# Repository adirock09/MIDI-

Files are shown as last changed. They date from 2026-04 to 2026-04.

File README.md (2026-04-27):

# MIRA-Custom-MIDI-
<br>

<br>
I started with layout It has 40 Keys in 10 x 4 Layout.Top two layers are for High octave and bottom two for Low octave the three sliders are for Filter,Reverb,Modulation and three encoders are for Volume, Tempo, Track control.I used Matrix so it uses less Gpios, It is based on Raspberry Pico.
PCB made in Kicad and modeling done in Fusion 360. Firmware is written in circuit python and uses Adafruit MIDI Library.

## Bill of Materials (BOM)

| Index | Component | Part Number | Source | Quantity | Unit Price (USD) | Total Price (USD) | Notes |
|---|---|---|---|---|---|---|---|
| 1 | Bittersweet Switch | MX2A-HC1B | stackskb.com | (Pack of 45)  × 1 | 17 | 17 | |
| 2 | Keycaps Set | MX Compatible Keycaps | meckeys.com | 8(pack of 5) | 1.1 | 8.8 | For 40 keys |
| 3 | Signal Diode | 1N4148TR | makerbazar.in | 4(pack of 10) | 0.15 | 0.6 | |
| 4 | Raspberry Pi Pico | SC0917 | makerbazar.in | 1 | 6.12 | 6.12 | |
| 5 | Slide Potentiometer 10K | PTL60-15R0-103B2 | Existing | 3 | 0 | Already have | |
| 6 | PCB Fabrication | SeedStudio PCB | seeedstudio.com | 1 | 51.11 |51.11 | |
| 7 | PCB Shipping | seedstudio Shipping | seeedstudio.com | 27.37 |  | 27.37 | |
| 8 | Rotary Encoder | EC11 | Existing | 3 | 0 | 0 | Already have |
| 9 | M3 Screws | M3x16mm | Existing | 4 | 0 | 0 | Already have |
| 10 | M3 Heat-set Inserts | M3 Heatset | Existing | 4 | 0 | 0 | Already have |

### Total Project Cost
**$111**

## Schematic & PCB
<br>
<br>


<br>

## 3d Render
<br>

<br>

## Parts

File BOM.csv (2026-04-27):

Index | Component | Part Number | Source | Quantity | Unit Price (USD) | Total Price (USD) | Notes
1 | Cherry MX Mechanical Keyswitch | MX2A-HC1B | stackskb.com | (Pack of 45) × 1 | 17 | 17
2 | Keycaps Set | MX Compatible Keycaps | meckeys.com | 8(pack of 5) | 1.1 | 8.8 | For 40 keys
3 | Signal Diode | 1N4148TR | makerbazar.in | 4(pack of 10) | 0.15 | 0.6
4 | Raspberry Pi Pico | SC0917 | makerbazar.in | 1 | 6.12 | 6.12
5 | Slide Potentiometer 10K | PTL60-15R0-103B2 | already have | 3 | 0 | 0
6 | PCB Fabrication | SeedStudioPCB | seeedstudio.com | 1 | 51.11 | 51.11
7 | PCB Shipping | SeedStudioPCB Shipping | seeedstudio.com | 1 | 27.37 | 27.37
8 | Rotary Encoder | EC11 | Existing | 3 | 0 | 0 | Already owned
9 | M3 Screws | M3x16mm | Existing | 4 | 0 | 0 | Already owned
10 | M3 Heat-set Inserts | M3 Heatset | Existing | 4 | 0 | 0 | Already owned
11 | Total |  |  |  |  | $111

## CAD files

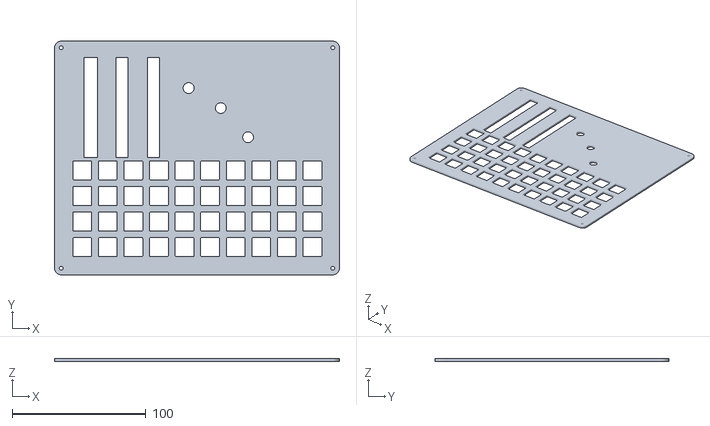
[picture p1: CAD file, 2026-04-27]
MIDI Controller/Production/TOP.stl
213.4 x 175.0 x 2.00

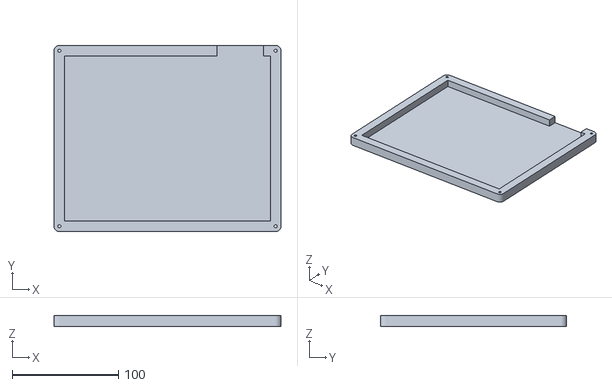
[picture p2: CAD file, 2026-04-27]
MIDI Controller/Production/BASE.stl
213.4 x 175.0 x 10.0

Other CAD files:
MIDI Controller/CAD/MIDI.f3d

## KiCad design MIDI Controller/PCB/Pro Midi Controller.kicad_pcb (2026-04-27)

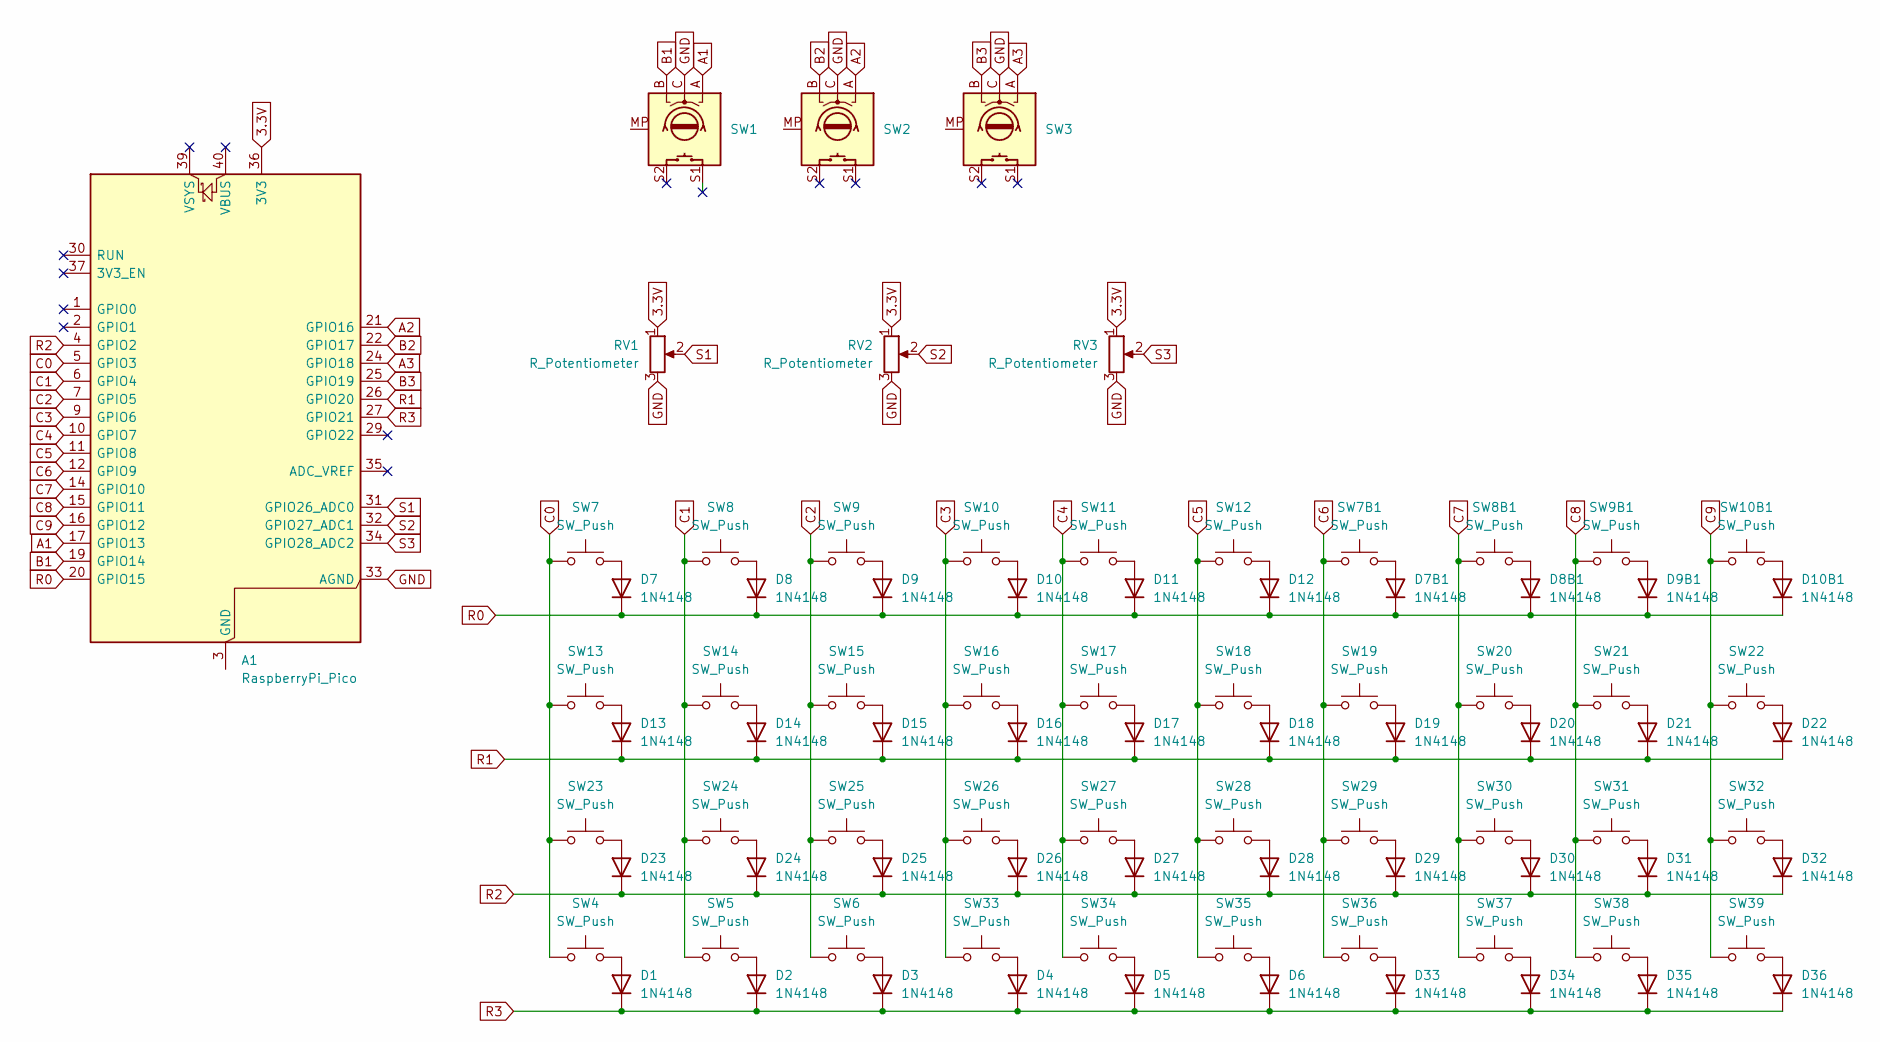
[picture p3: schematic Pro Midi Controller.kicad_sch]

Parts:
A1: RaspberryPi_Pico; RaspberryPi_Pico_Common_Unspecified
D1, D2, D3, D4, D5, D6, D7, D7B1, D8, D8B1, D9, D9B1, D10, D10B1, D11, D12, D13, D14, D15, D16, D17, D18, D19, D20, D21, D22, D23, D24, D25, D26, D27, D28, D29, D30, D31, D32, D33, D34, D35, D36: 1N4148; D_DO-35_SOD27_P7.62mm_Horizontal
RV1, RV2, RV3: R_Potentiometer; Potentiometer_Bourns_PTA6043_Single_Slide
SW1, SW2, SW3: RotaryEncoder_Switch_MP; RotaryEncoder_Alps_EC11E-Switch_Vertical_H20mm
SW4, SW5, SW6, SW7, SW7B1, SW8, SW8B1, SW9, SW9B1, SW10, SW10B1, SW11, SW12, SW13, SW14, SW15, SW16, SW17, SW18, SW19, SW20, SW21, SW22, SW23, SW24, SW25, SW26, SW27, SW28, SW29, SW30, SW31, SW32, SW33, SW34, SW35, SW36, SW37, SW38, SW39: SW_Push; SW_Cherry_MX_1.00u_PCB

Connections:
3.3V: A1.36 (3V3), RV1.1, RV2.1, RV3.1
A1: A1.17 (GPIO13), SW1.A
A2: A1.21 (GPIO16), SW2.A
A3: A1.24 (GPIO18), SW3.A
B1: A1.19 (GPIO14), SW1.B
B2: A1.22 (GPIO17), SW2.B
B3: A1.25 (GPIO19), SW3.B
C0: A1.5 (GPIO3), SW4.1, SW7.1, SW13.1, SW23.1
C1: A1.6 (GPIO4), SW5.1, SW8.1, SW14.1, SW24.1
C2: A1.7 (GPIO5), SW6.1, SW9.1, SW15.1, SW25.1
C3: A1.9 (GPIO6), SW10.1, SW16.1, SW26.1, SW33.1
C4: A1.10 (GPIO7), SW11.1, SW17.1, SW27.1, SW34.1
C5: A1.11 (GPIO8), SW12.1, SW18.1, SW28.1, SW35.1
C6: A1.12 (GPIO9), SW7B1.1, SW19.1, SW29.1, SW36.1
C7: A1.14 (GPIO10), SW8B1.1, SW20.1, SW30.1, SW37.1
C8: A1.15 (GPIO11), SW9B1.1, SW21.1, SW31.1, SW38.1
C9: A1.16 (GPIO12), SW10B1.1, SW22.1, SW32.1, SW39.1
GND: A1.33 (AGND), RV1.3, RV2.3, RV3.3, SW1.C, SW2.C, SW3.C
unnamed: A1.3 (GND), A1.8 (GND), A1.13 (GND), A1.18 (GND), A1.23 (GND), A1.28 (GND), A1.38 (GND)
unnamed: D1.2 (A), SW4.2
unnamed: D2.2 (A), SW5.2
unnamed: D3.2 (A), SW6.2
unnamed: D4.2 (A), SW33.2
unnamed: D5.2 (A), SW34.2
unnamed: D6.2 (A), SW35.2
unnamed: D7.2 (A), SW7.2
unnamed: D7B1.2 (A), SW7B1.2
unnamed: D8.2 (A), SW8.2
unnamed: D8B1.2 (A), SW8B1.2
unnamed: D9.2 (A), SW9.2
unnamed: D9B1.2 (A), SW9B1.2
unnamed: D10.2 (A), SW10.2
unnamed: D10B1.2 (A), SW10B1.2
unnamed: D11.2 (A), SW11.2
unnamed: D12.2 (A), SW12.2
unnamed: D13.2 (A), SW13.2
unnamed: D14.2 (A), SW14.2
unnamed: D15.2 (A), SW15.2
unnamed: D16.2 (A), SW16.2
unnamed: D17.2 (A), SW17.2
unnamed: D18.2 (A), SW18.2
unnamed: D19.2 (A), SW19.2
unnamed: D20.2 (A), SW20.2
unnamed: D21.2 (A), SW21.2
unnamed: D22.2 (A), SW22.2
unnamed: D23.2 (A), SW23.2
unnamed: D24.2 (A), SW24.2
unnamed: D25.2 (A), SW25.2
unnamed: D26.2 (A), SW26.2
unnamed: D27.2 (A), SW27.2
unnamed: D28.2 (A), SW28.2
unnamed: D29.2 (A), SW29.2
unnamed: D30.2 (A), SW30.2
unnamed: D31.2 (A), SW31.2
unnamed: D32.2 (A), SW32.2
unnamed: D33.2 (A), SW36.2
unnamed: D34.2 (A), SW37.2
unnamed: D35.2 (A), SW38.2
unnamed: D36.2 (A), SW39.2
R0: A1.20 (GPIO15), D7.1 (K), D7B1.1 (K), D8.1 (K), D8B1.1 (K), D9.1 (K), D9B1.1 (K), D10.1 (K), D10B1.1 (K), D11.1 (K), D12.1 (K)
R1: A1.26 (GPIO20), D13.1 (K), D14.1 (K), D15.1 (K), D16.1 (K), D17.1 (K), D18.1 (K), D19.1 (K), D20.1 (K), D21.1 (K), D22.1 (K)
R2: A1.4 (GPIO2), D23.1 (K), D24.1 (K), D25.1 (K), D26.1 (K), D27.1 (K), D28.1 (K), D29.1 (K), D30.1 (K), D31.1 (K), D32.1 (K)
R3: A1.27 (GPIO21), D1.1 (K), D2.1 (K), D3.1 (K), D4.1 (K), D5.1 (K), D6.1 (K), D33.1 (K), D34.1 (K), D35.1 (K), D36.1 (K)
S1: A1.31 (GPIO26_ADC0), RV1.2
S2: A1.32 (GPIO27_ADC1), RV2.2
S3: A1.34 (GPIO28_ADC2), RV3.2

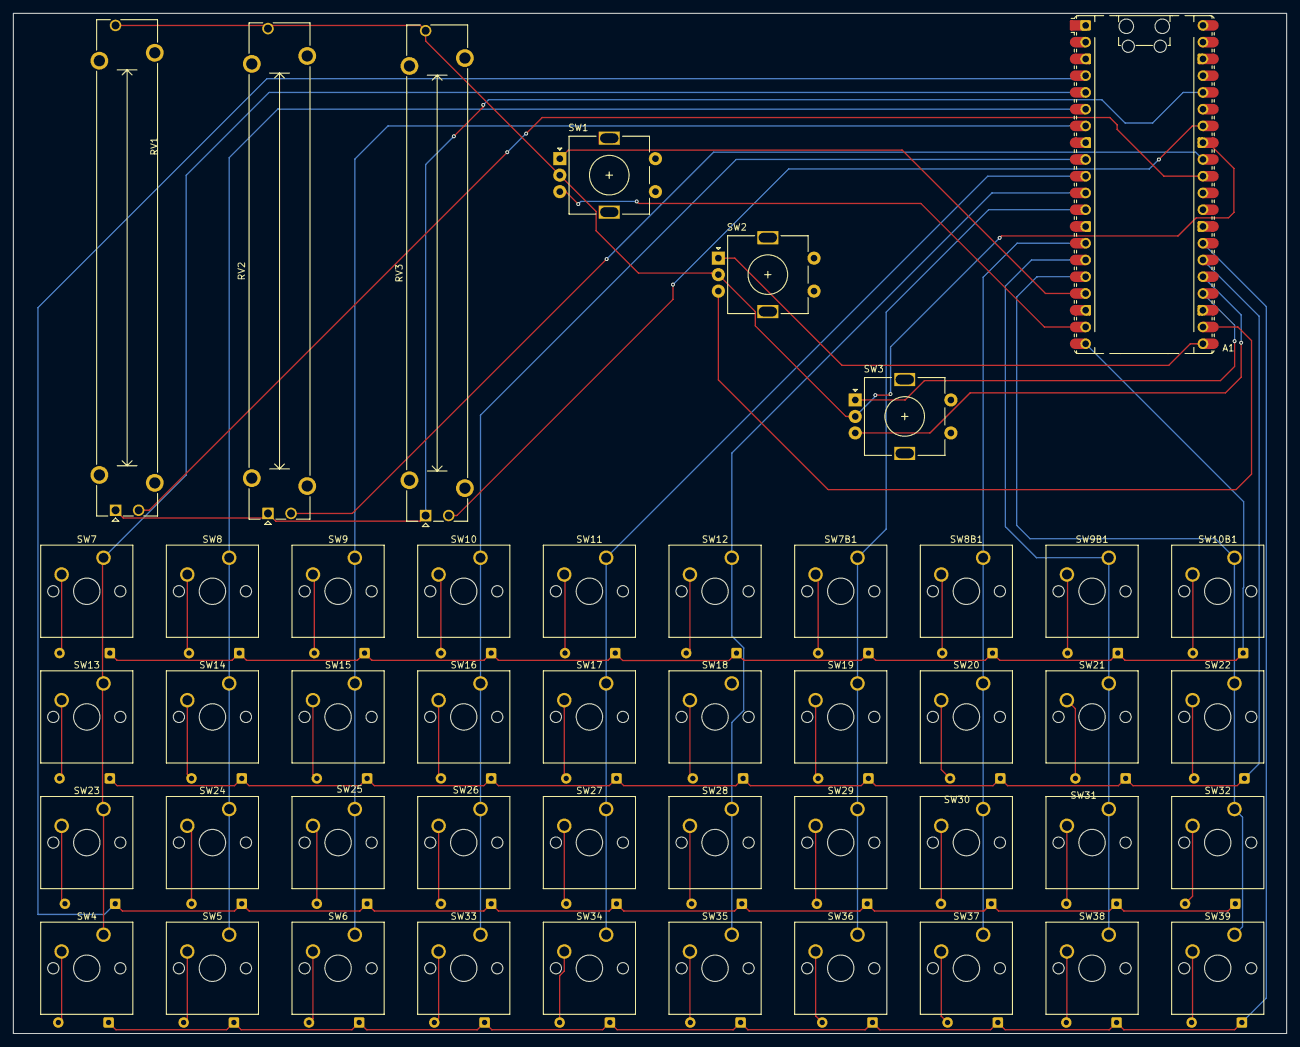
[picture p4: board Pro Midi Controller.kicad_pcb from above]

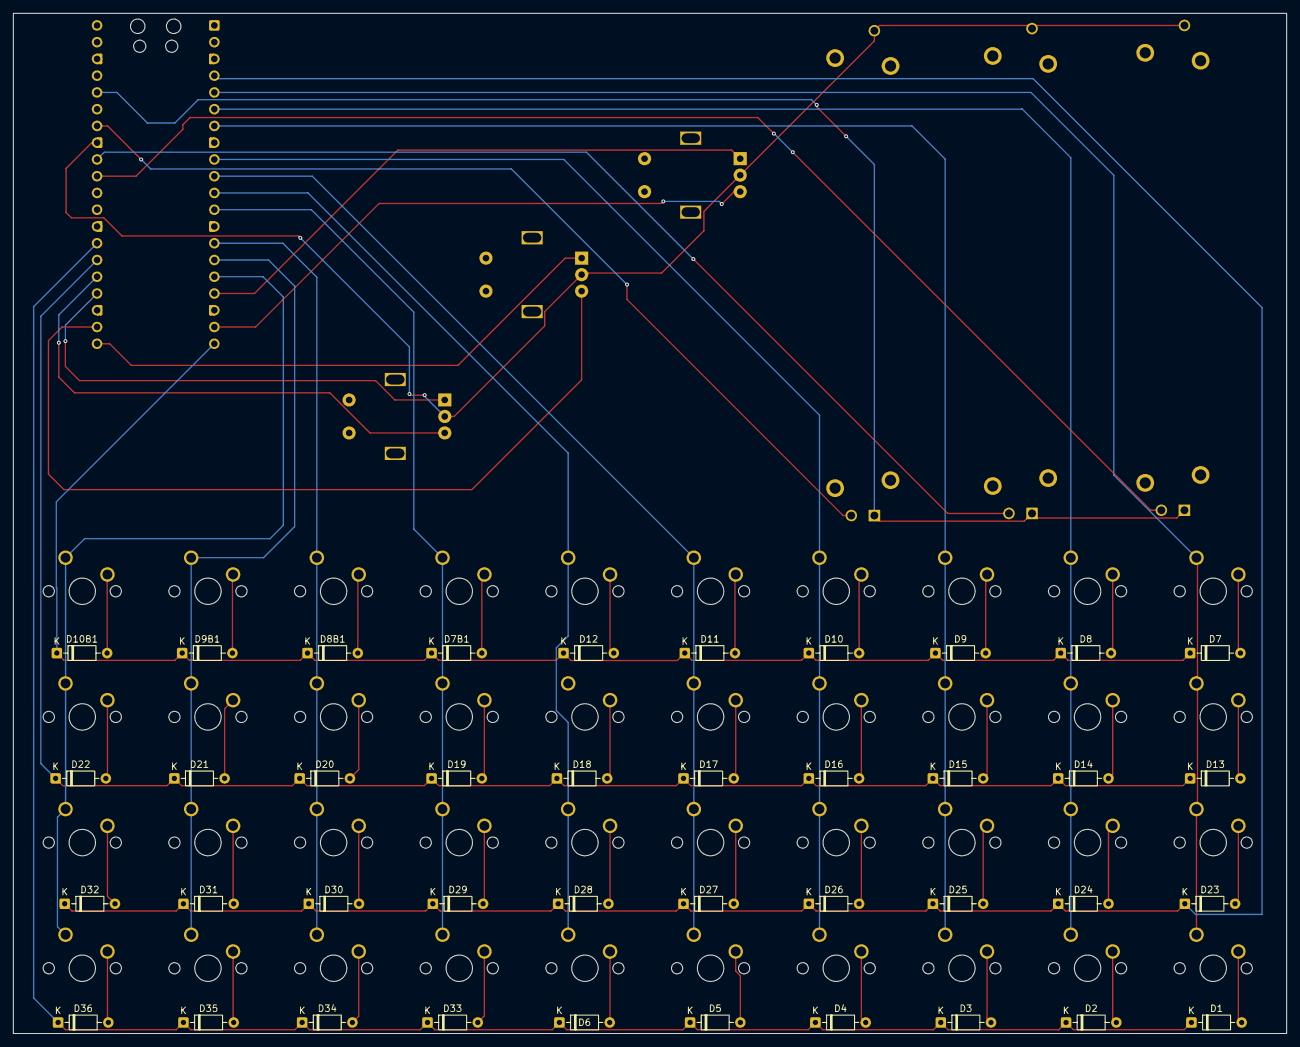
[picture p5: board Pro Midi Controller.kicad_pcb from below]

Board: 2 copper layers, 193.0 x 154.7 mm, 87 parts (40 on the bottom side), 66 nets.

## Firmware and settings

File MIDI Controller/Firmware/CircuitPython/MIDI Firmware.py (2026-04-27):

import board
import digitalio
import analogio
import rotaryio
import usb_midi
import time

import adafruit_midi
from adafruit_midi.note_on import NoteOn
from adafruit_midi.note_off import NoteOff
from adafruit_midi.control_change import ControlChange

# ---------------- MIDI ----------------

midi = adafruit_midi.MIDI(
    midi_out=usb_midi.ports[1],
    out_channel=0
)

# ---------------- MATRIX PINS ----------------

ROWS = [
    board.GP2,
    board.GP3,
    board.GP4,
    board.GP5
]

COLS = [
    board.GP6,
    board.GP7,
    board.GP8,
    board.GP9,
    board.GP10,
    board.GP11,
    board.GP12,
    board.GP13,
    board.GP14
]

row_pins = []
col_pins = []

for r in ROWS:
    pin = digitalio.DigitalInOut(r)
    pin.direction = digitalio.Direction.OUTPUT
    pin.value = True
    row_pins.append(pin)

for c in COLS:
    pin = digitalio.DigitalInOut(c)
    pin.direction = digitalio.Direction.INPUT
    pin.pull = digitalio.Pull.UP
    col_pins.append(pin)

pressed = [[False]*9 for _ in range(4)]

# ---------------- NOTE MAP ----------------

HIGH_NOTES = [
72,74,76,77,79,81,83,84,86,
88,89,91,93,95,96,98,100,101
]

LOW_NOTES = [
48,50,52,53,55,57,59,60,62,
64,65,67,69,71,72,74,76,77
]

# ---------------- SLIDERS ----------------

slider1 = analogio.AnalogIn(board.GP26)
slider2 = analogio.AnalogIn(board.GP27)
slider3 = analogio.AnalogIn(board.GP28)

last_slider1 = 0
last_slider2 = 0
last_slider3 = 0

# ---------------- ENCODERS ----------------

enc1 = rotaryio.IncrementalEncoder(board.GP16, board.GP17)
enc2 = rotaryio.IncrementalEncoder(board.GP18, board.GP19)
enc3 = rotaryio.IncrementalEncoder(board.GP20, board.GP21)

last_enc1 = enc1.position
last_enc2 = enc2.position
last_enc3 = enc3.position

# ---------------- KEY SCAN ----------------

def scan_matrix():

    for r in range(4):

        row_pins[r].value = False

        for c in range(9):

            if not col_pins[c].value:

                if not pressed[r][c]:

                    if r < 2:
                        note = HIGH_NOTES[r*9 + c]
                    else:
                        note = LOW_NOTES[(r-2)*9 + c]

                    midi.send(NoteOn(note,120))
                    pressed[r][c] = True

            else:

                if pressed[r][c]:

                    if r < 2:
                        note = HIGH_NOTES[r*9 + c]
                    else:
                        note = LOW_NOTES[(r-2)*9 + c]

                    midi.send(NoteOff(note,0))
                    pressed[r][c] = False

        row_pins[r].value = True

# ---------------- SLIDERS ----------------

def read_sliders():

    global last_slider1
    global last_slider2
    global last_slider3

    v1 = slider1.value >> 9
    v2 = slider2.value >> 9
    v3 = slider3.value >> 9

    if abs(v1 - last_slider1) > 2:
        midi.send(ControlChange(74,v1))
        last_slider1 = v1

    if abs(v2 - last_slider2) > 2:
        midi.send(ControlChange(91,v2))
        last_slider2 = v2

    if abs(v3 - last_slider3) > 2:
        midi.send(ControlChange(1,v3))
        last_slider3 = v3

# ---------------- ENCODERS ----------------

def read_encoders():

    global last_enc1
    global last_enc2
    global last_enc3

    pos = enc1.position

    if pos != last_enc1:

        change = pos - last_enc1

        if change > 0:
            midi.send(ControlChange(7,65))
        else:
            midi.send(ControlChange(7,63))

        last_enc1 = pos

    pos = enc2.position

    if pos != last_enc2:

        change = pos - last_enc2

        if change > 0:
            midi.send(ControlChange(16,65))
        else:
            midi.send(ControlChange(16,63))

        last_enc2 = pos

    pos = enc3.position

    if pos != last_enc3:

        change = pos - last_enc3

        if change > 0:
            midi.send(ControlChange(19,65))
        else:
            midi.send(ControlChange(19,63))

        last_enc3 = pos

# ---------------- MAIN LOOP ----------------

while True:

    scan_matrix()

    read_sliders()

    read_encoders()

    time.sleep(0.005)
